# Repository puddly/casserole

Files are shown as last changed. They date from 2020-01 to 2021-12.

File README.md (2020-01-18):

# Casserole
An open source alternative to the now-defunct [Green Bean adapter](https://github.com/GEMakers/green-bean) to monitor and control GE appliances through their RJ45 port.

# Installation

```sh
# Clone the repo
git clone https://github.com/puddly/casserole
cd casserole

# Setup a new virtual Python env (optional but recommended)
python3 -m venv venv
source venv/bin/activate

# Install dependencies
pip install -r requirements.txt

# Compile and upload the firmware to your ESP32
platformio run -t upload -v -e esp32 --upload-port=/dev/cu.SLAB_USBtoUART

# Run the host software and see what your appliance is doing
python protocol.py
```

## What works
1. All bus messages are sent back to the computer, including ones sent by the appliance user input boards.
2. Messages can be sent to the bus.

## What doesn't work
1. Other devices occasionally interrupt the adapter's messages. I'm not sure how devices take turns when sending data over the bus.
2. GE/FirstBuild's open source SDK is incomplete and does not document any way to remotely start some appliances (like my washer).

## Hardware
I don't know much about building electronics but here are the parts I've used:

 - ESP32 dev kit ([I use this one with built-in RGB LEDs](https://www.tindie.com/products/ddebeer/esp32-dev-board-wifibluetooth/) but any should work)
 - 3.3v to 5V bus transceiver ([TI SN74LVC2T45](https://www.ti.com/lit/ds/symlink/sn74lvc2t45.pdf))
 - 5V regulator ([ST LD1117](https://www.st.com/content/ccc/resource/technical/document/datasheet/99/3b/7d/91/91/51/4b/be/CD00000544.pdf/files/CD00000544.pdf/jcr:content/translations/en.CD000005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), though just about any should work). I've read that the ESP32 can draw up to 600mA in 100ms bursts when in AP mode but ordinarily draws about 40mA.

Wiring:

 - Regulate the 9V from the GE bus down to 5V and connect it both your ESP32's `Vin` pin and to the high voltage input of the bus transceiver.
 - Connect the ESP32's 3.3V pin to the low voltage input of the bus transceiver.
 - Tie together the ESP32's second UART's RX and TX pins (16 and 17) and connect them to the low voltage input of the bus transceiver.
 - Connect pin 18 (though any will work) to the direction control of the bus transceiver.

```
[insert proper diagram here]
```

## Low-level details

### RJ45 Port
The RJ45 (Ethernet) port on some GE appliances exposes a bus that allows for communication with the appliance's controller board. The three pins are labeled `GND`, `COMM`, and `9V`.

The COMM bus uses 5V logic and is an inverted UART at 19,200 baud.

### Protocol
I've been unable to acquire an actual Green Bean module so all of the information here is based on what I can capture from my washing machine. Here is a sample packet:

    e2 23 22 2d f1 03 f1 2e 0e 03 03 01 19 15 05 2a 00 0a f1 76 fc 0f 0a f1 39 01 03 f1 33 01 5d 9c 30 e3 e1

All packets begin with `e2` and end with `e3 e1` (although very rarely just `e3`). The byte `e0` acts as an escape character and all instances of `e0`, `e1`, `e2`, and `e3` in the body of the packet are escaped with `e0` (so `aa e0 bb e1 cc` becomes `aa e0 e0 bb e0 e1 cc`).

Each packet has a simple structure:
 
 - (1 byte) `e2`. Everything after this but before the final `e1` is encoded using the above scheme.
 - (1 byte) packet destination
 - (1 byte) total packet length (*before* the `e[0-3]` bytes have been escaped)
 - (1 byte) packet sender
 - (1 byte) command type
 - (? bytes) data
 - (2 bytes) CRC-16 checksum of the entire packet up until the start of the checksum bytes. It is a 16-bit CRC with the following parameters:

       width=16  poly=0x1021  init=0xe300  refin=false  refout=false  xorout=0x0000  check=0x5b10  residue=0x0000  name=(none)

    As before, this is computed on the packet payload before the `e[0-3]` bytes have been escaped. Interestingly, this specific CRC-16 has the following property:

       crc16(packet_until_checksum || crc16(packet_until_checksum)) == 0x0000

 - (1 or 2 bytes) `e1 e3`, although very rarely a packet is sent (consistently) with `e3` missing.

The packet command type determines how the `data` is interpreted. A command type of `f1` is used internally for all reads/writes and has the following structure:

 - (1 byte) `f1`
 - (1 byte) number of reads/writes encoded in `data`
 - A list of commands:
   - (1 byte) `f0` is read, `f1` is write.
   - (1 byte) endpoint ID
   - (1 byte) (This and the following bytes are absent in read requests and write acknowledgements) size of read respons or data to be written
   - (? bytes) data

The Green Bean uses a different syntax for reads (writes TBD) for what it calls ERDs:

 - (1 byte) `f0`
 - (1 byte) `01` for reads
 - (2 byte) 16-bit ERD, big-endian

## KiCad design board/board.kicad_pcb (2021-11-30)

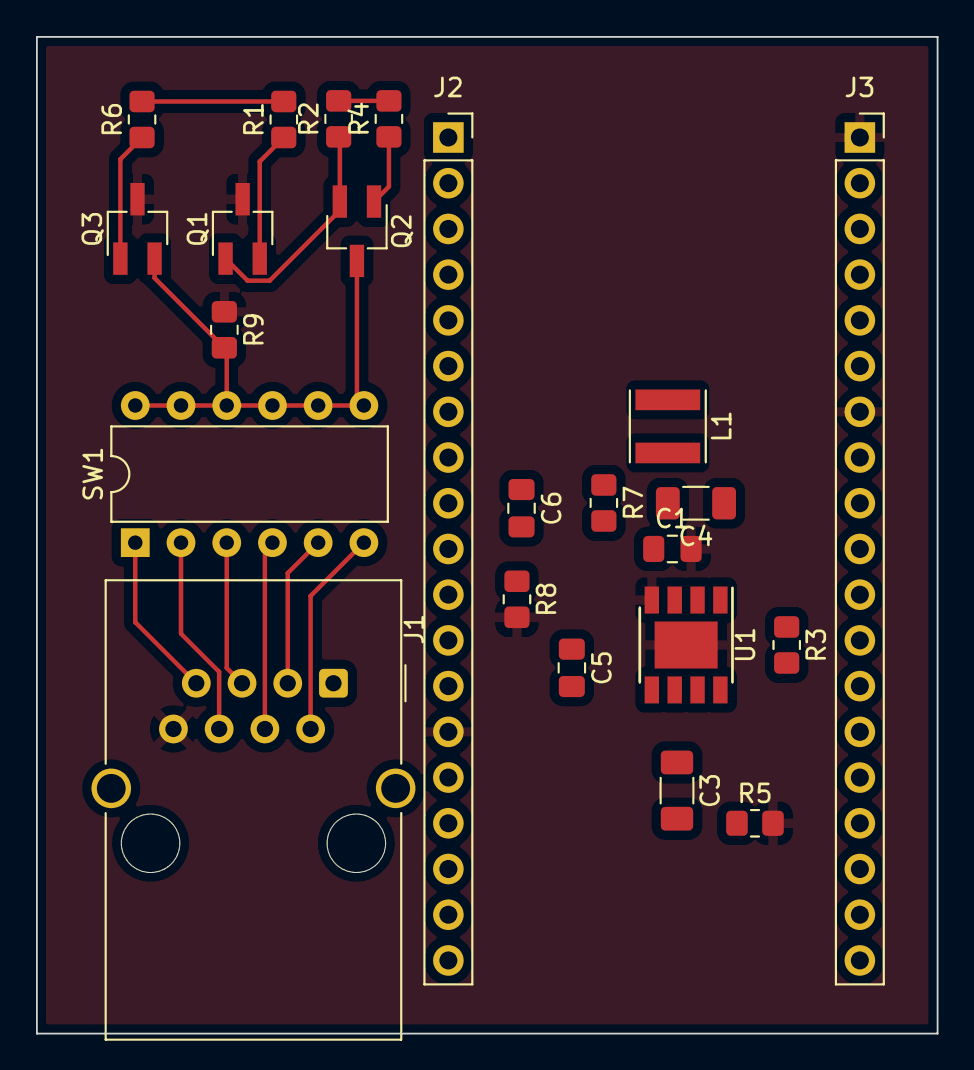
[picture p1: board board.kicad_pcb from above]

Board: 2 copper layers, 50.0 x 55.4 mm, 23 parts (0 on the bottom side), 21 nets.

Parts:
C1: 10µF; C_0805_2012Metric_Pad1.18x1.45mm_HandSolder
C3: 6.8nF; C_1206_3216Metric_Pad1.33x1.80mm_HandSolder
C4: 10nF; C_1206_3216Metric_Pad1.33x1.80mm_HandSolder
C5, C6: 22µF; C_0805_2012Metric_Pad1.18x1.45mm_HandSolder
J1: RJ45; RJ45_Wuerth_7499010001A_Horizontal
J2, J3: Conn_01x19_Female; PinSocket_1x19_P2.54mm_Vertical
L1: 10µH; L_Vishay_IFSC-1515AH_4x4x1.8mm
Q1, Q2, Q3: Q_NMOS_DGS; SC-59_Handsoldering
R1, R9: ?; R_0805_2012Metric_Pad1.20x1.40mm_HandSolder
R2, R4, R6: 47k; R_0805_2012Metric_Pad1.20x1.40mm_HandSolder
R3: 100k; R_0805_2012Metric_Pad1.20x1.40mm_HandSolder
R5: 6.8k; R_0805_2012Metric_Pad1.20x1.40mm_HandSolder
R7: 53.3k; R_0805_2012Metric_Pad1.20x1.40mm_HandSolder
R8: 10k; R_0805_2012Metric_Pad1.20x1.40mm_HandSolder
SW1: SW_DIP_x06; DIP-12_W7.62mm
U1: AP6502; Diodes_SO-8EP

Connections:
+3V3: J2.1, R1.2, R6.2
+5V: C5.1, C6.1, J2.19, L1.2, R2.2, R4.2, R7.1
GEA_3.3V_RX: J3.12, Q3.1 (D), R6.1
GEA_3.3V_TX: J3.11, Q1.2 (G), R1.1
GEA_BUS: Q2.3 (S), Q3.2 (G), R9.2, SW1.7, SW1.8, SW1.9, SW1.10, SW1.11, SW1.12
GND: C1.2, J1.8, J2.14, J3.1, J3.7, Q1.3 (S), Q3.3 (S), R5.2, R8.2, R9.1, U1.4 (GND), U1.9 (EP)
unnamed: C3.1, U1.6 (COMP)
unnamed: C3.2, R5.1
unnamed: C4.1, U1.1 (BST)
unnamed: C4.2, L1.1, U1.3 (SW)
unnamed: C5.2, C6.2, R7.2, R8.1, U1.5 (FB)
unnamed: J1.2, SW1.6
unnamed: J1.3, SW1.5
unnamed: J1.4, SW1.4
unnamed: J1.5, SW1.3
unnamed: J1.6, SW1.2
unnamed: J1.7, SW1.1
unnamed: Q1.1 (D), Q2.2 (G), R2.1
unnamed: Q2.1 (D), R4.1
unnamed: R3.2, U1.7 (EN)
VCC: C1.1, J1.1, R3.1, U1.2 (IN)

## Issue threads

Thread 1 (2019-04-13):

Comment/help

wied03, 2019-04-13:
@puddly - Have you looked @ https://github.com/GEMakers/gea-plugin-water-heater/blob/master/hewh-interface.docx ? Different appliance but might help. I analyzed a GE connect's communication with my water heater but I hadn't yet figured out 19200 baud/inverted so thanks for that piece of info.

puddly, 2019-04-14:
@wied03 I have not, thanks for the document. All of those commands and responses seem to be implemented on top of the base layer that I'm almost done figuring out so I think replacing the USB adapter will not make the main [`gea-plugin-water-heater`](https://github.com/GEMakers/gea-plugin-water-heater/) module work any differently.

wied03, 2019-04-14:
I've since found that the GE connect module does not adhere to that guide
at all. It instead follows write read commands like the SDK and your readme
mentioned. I took apart the ERD data and it worked like the SDK did.

I need to figure out the hash as well. Maybe it's just a simple checksum
like ipv4 uses?

sent from my mobile device

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

puddly, 2019-04-14:
@wied03 I've updated the README a few times, including a description of the checksum. It's implemented in the Python script that parses the packets.

Closed 2019-04-15.

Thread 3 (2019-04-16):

Sample Green Bean traffic

puddly, 2019-04-16:
I'm looking for somebody willing to donate an hour of their time (or their Green Bean for a few days) by capturing some sample USB and bus traffic from a Green Bean.

 -  For capturing the traffic from the computer to the Green Bean, you can either use [Wireshark](https://wiki.wireshark.org/CaptureSetup/USB) and capture the USB packets, or you can just patch the [Node.js module's](https://github.com/GEMakers/gea-adapter-usb/blob/master/index.js#L126) `sendPacket` and `receiveNextPacket` functions to write the sent/received data to a file.

 - For capturing the traffic to the module, you can use a $12 USB logic analyzer and [PulseView](https://sigrok.org/wiki/Downloads). I found 500KHz to be a reasonable sample rate. Just plug in the adapter and hit the <kbd>Run</kbd> button. You will somehow need to tap into the bus, which will require you to either sacrifice a short Ethernet cable and carefully cut into housing in the middle to clip into the GND (brown) and COMM (brown/white) wires:
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

   Or find some convenient place on the Green Bean to probe them, like:

    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

    There is a four-pin header on the Green Bean but it might just be for communicating with the microcontroller.

@Hixie

Hixie, 2019-04-16:
If you send me precise details for how to do it (commands and the hardware to do it), I'm happy to just do it (happy to send you money to pay for the hardware, too). Otherwise I can try to figure it out but it might be a few months as I'm rather busy at the moment.

puddly, 2019-04-16:
@Hixie  I can mail you all the required hardware if you're in the US but I can't guarantee the software will work flawlessly. If nobody else is interested and I can't figure it out by myself in the next couple of weeks, I'll send you an email.

jallen2281, 2019-05-28:
@puddly do you use facebook or another messaging service? I'd be happy to help with this as well.

puddly, 2019-05-28:
@jallen2281 I use Telegram but I've also setup a [Gitter chatroom](https://gitter.im/casserole-dev/community) that you can sign into with your GitHub account if that's easier.

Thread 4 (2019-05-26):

Designing a PCB

puddly, 2019-05-26:
My goal is to have a self-contained device that is powered by either the RJ45 port's 9V pin or by a microUSB connector that can communicate with a computer over usb or WiFi.

I'm currently using a dev kit built around the ESP32-WROOM-32 because it has:

 - two hardware UARTs (one for USB and one for communicating with the bus).
 - the UARTs support signal inversion (the bus uses 5V logic and is pulled down to 0V).
 - [first-party support](https://docs.espressif.com/projects/esp-idf/en/latest/api-reference/system/freertos.html) for FreeRTOS.
 - Bluetooth and WiFi.

I'd like wireless connectivity so I really see two ways to do this:

 - Make a "shield" for an existing dev board (e.g. the ESP32 dev kit). This saves time because pre-made dev boards already come with a voltage regulator and a USB-serial interface. All that needs to be done is to solder a few headers and a 9V->5V regulator to an unpopulated PCB. Plus the dev board can be repurposed if you ever get rid of your GE appliances.

 - Designing around a wireless module (e.g. the ESP32-WROOM-32). This would avoid having unnecessary components and will result in a simpler board but will take more time to solder together.

Component-wise, we need:

 - USB-serial converter (anything but the CH340).
 - a dual-supply transceiver for level shifting with direction and enable pins (maybe the [SN74LVC2T45](https://www.ti.com/lit/ds/symlink/sn74lvc2t45.pdf)?).
 - a component (or two) that converts 9V to both 5V and 3.3V and provides enough current for wireless operation (ESP32 needs at least 250mA, I think).
 - RJ45 port. Tying together the two possible locations of the 9V pin (the GND and COMM stay fixed) allows for handling both normal and crossover ethernet cables.

@jallen2281

mulcmu, 2020-08-10:
Here was my KiCad schematic for a "shield" using parts recommended above.  Any comments or suggestions before routing the PCB?

[OnionStraws Draft.pdf](https://github.com/puddly/casserole/files/5051666/OnionStraws.Draft.pdf)

puddly, 2020-08-10:
Thanks for the help! I've been hoping to finish this project for a while but I have no experience with actually designing PCBs so it's been a little hard to get started.

Here's some more info that I've found in the meantime:

1. Almost like I2C, the bus is being pulled down to GND by a 4.7k resistor.
   - Actively driving the bus down to GND with the chip I was originally using might not be a good idea because we can collide with another device concurrently pulling the bus up to 5V and possibly damage something. I think only pulling the bus up to 5V during transmission and letting it fall back down to GND will be a safer approach.
   - Removing the need for the SN74LVC2T45 chip reduces the cost a little.
   - Implementing collision detection by receiving and transmitting concurrently might also be a good idea, as we can just immediately stop transmitting a message if what we receive from the bus doesn't match what we expect.
   - The ESP-32's UART's RX and TX pins can be inverted in software, which might simplify the design little?

2. The input voltage on the RJ45 apparently can go as high as 16V on some appliances, not just 9V as I had measured on my machine.
   - The LD1117S50TR can't handle this high of an input voltage so we'd need a new voltage regulator.
   - Some people [have also reported](https://esp32.com/viewtopic.php?t=2662#p16066) that their off-brand ESP-32 dev kits briefly draw up to 750mA when scanning for wireless networks.

3. There are multiple footprints for the many ESP-32 dev kits available online. You can find the schematics and reference design documents for the different dev boards [on Espressif's website](https://docs.espressif.com/projects/esp-idf/en/latest/esp32/hw-reference/modules-and-boards.html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) but I think basing the design around the ESP-WROOM-32 DEVKIT V4 is or the smaller ESP32-PICO-KIT V4.1 is a good idea. They're both $10 from Digikey. Alternatively you can get a non-standard design for about $4 off of AliExpress. I'll have to investigate the footprints of the different boards a little more to see which ones are the most compatible.

mulcmu, 2020-08-11:
I've done a few custom boards for hobby stuff.  Just got a new GE Washer and Dryer.  Was looking to push cycle done and maybe time remaining to home assistant.

1.  Have you tried any alternate arrangements for RX/TX connection?  Still need something to shift from 3.3V to 5V?

2.  Looks like there are some 1A 35V linear regulators to get the 5V supply (like MC7805BDTRKGOSCT-ND).  I will look into a small DC/DC buck converter.  More parts and expense but more efficient for something powered 24/7.

3.  My generic modules from Amazon had the ESP-WROOM-32 DEVKIT V4 pinout but are a bit more compact.  The ESP module pcb antenna didn't hang out from the base PCB.

puddly, 2020-08-11:
1. The whole 5V bus with a pull-down level shifting problem is what's really tripping me up with this whole project so could you clarify what you mean by an alternate arrangement? All of the devices on the bus are 5V so I'm trying to get the ESP32 to act like everything else. I believe the official Green Bean used a pair of optocouplers for the level shifting.

2. The bus passes around data around on my machine about once per second so the larger power supply might be necessary if the ESP-32 will be transmitting frequently. I think with some sort of bus packet filters microcontroller-side it'd be possible to keep the ESP-32 in a low-power state for quite some time before it wakes up, especially if the common use case would be to just notify HA of a couple of events periodically.

3. [This is the one](https://www.tindie.com/products/ddebeer/esp32-dev-board-wifibluetooth/) I'm currently using and the PCB has a big cutout where the ESP-32's trace antenna is sitting. I'll have to compare its current draw to the Amazon ones.

puddly, 2020-09-21:
Hmm, I wasn't aware there could be multiple buses on a single RJ45. That does complicate things.

The ESP-32 definitely has enough free pins to do simultaneous TX/RX on all of those but they have to be bigbanged instead of relying on the built-in UARTs and my code doesn't really support concurrency at the moment (though the ESP-32 has first-party support for FreeRTOS, which should make the rewrite trivial).

mattgallion, 2021-11-30:
Hey guys,

I just bought a W&D and am interested in integrating into Home Assistant too. I have a lot of experience with PCB design so I can help with layout and can do some board runs too.

puddly, 2021-11-30:
Thanks for your interest!

I've just pushed my attempt at a schematic and an unrouted board to the Git repo under the `board/` folder.  It was draw up with a KiCad nightly build so it may not open properly with the current stable release.

Unfortunately, a recent package theft has left me without any 5V regulators capable of accepting 9V-16V input (and I won't be able to get replacements until early next year due to the chip shortage) so this project is not seeing much attention these days.

The only portion of the PCB that I'm still struggling with at the moment is the inverted level shifting with the GE bus pulldown.  If you can suggest a way to do this while accepting "normal" logic levels from the microcontroller, I think the hardware is close to being done. At least in the eyes of someone who has designed exactly two PCBs with no active components 😄.

---

Attached is the schematic in case there are any custom symbols/footprints on the board that don't open:

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

jallen2281, 2021-11-30:
I was chatting with a GE repair man today and he uses a "Black Bean" module. It has firmware flashing capabilities as well as everything the green bean has. Just thought it was interesting.

jallen2281, 2021-11-30:
Not sure if this will help someone, but the chip in use on the original module is this: https://www.microchip.com/en-us/product/PIC24FJ256GB106

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

mattgallion, 2021-12-02:
@puddly Any reason why you're using a switching regulator for the 5V instead of a linear regulator? I assume your goal is to minimize losses in power, and I'm curious if you know what the current supply capability from the bus is?

I had started my own attempt based on some ideas I found online (https://circuitcellar.com/resources/ee-tips/one-wire-rs-232-half-duplex-ee-tip-135/) but havent tested anything yet. See attached schematic, it's **by no means complete**. I used a dual inverter to fix the inverted levels, and a digital isolator for the level shifting.

@jallen2281 Thats funny, I was working on my own adapter (copying from the greenbean) and I was going to call it blackbean.

[BlackBeanSchematic_0.1.pdf](https://github.com/puddly/casserole/files/7644192/BlackBeanSchematic_0.1.pdf)

puddly, 2021-12-02:
> I assume your goal is to minimize losses in power, and I'm curious if you know what the current supply capability from the bus is?

I don't, unfortunately. I will poke around in my washer when I get a minute.

My understanding is that the ESP32 draws about 40mA when not actively using WiFi, 150mA when using WiFi, and briefly exceeds 500-700mA when scanning for networks.  The worst case scenario would be regulating 16V down to 5V and supplying 150mA of current, so a linear regulator would dissipate at least 1.65W.

> I used a dual inverter to fix the inverted levels, and a digital isolator for the level shifting.

Thanks for the link, I wish I had found that page sooner. I think your schematic incorporates design 3 in that article, which suppresses the "local echo". For collision detection, loopback reception is actually desirable because the firmware would compare each transmitted character (or bit) to the received one and stop transmitting if they aren't identical.

> Thats funny, I was working on my own adapter (copying from the greenbean) and I was going to call it blackbean.

I believe there's also a Navy Bean.  This is arguably the most important part of the project but thankfully there are [many other beans to choose from](https://en.wikipedia.org/wiki/Bean#Common_genera_and_species_of_beans).  An irregular, kidney shaped PCB with red solder mask might be interesting...

mulcmu, 2021-12-09:
> Looks like the hardware & interface has been changed. My RJ45 port doesn't have pin 7 populated. I was still getting 14 Vdc between pin 1 & 8. It appears pins 3 to 6 all could have connections to the main PCB. Haven't hooked it up to a scope yet...

Finally hooked it up to scope.  Pins 3 & 4 seemed to have a constant 5V and 5 & 6 were at ground with a bit of noise.  I couldn't detect anything that looked like a signal.  I ordered a `U+ CONNECT MODULE PBX23W00Y0` to try to get some insight into what was going on with this alternate interface.

mulcmu, 2022-01-04:
I've made some progress on getting my dryer integrated into HA.  It has the half duplex GE bus on pin 7 of the RJ45.  I didn't have luck with mosfet based level shifting using 2N7000 or TXS0104E level shifting IC.   Finally got rx & tx working on breadboard with dryer using non-inverting buffer IC.
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

I was using a adjustable DC/DC switching module for the 5v power supply (https://www.amazon.com/gp/product/B01MQGMOKI/).  The dryer was able to power both the ESP32 and `U+CONNECT MODULE`  at the same time.

ESPHome custom component and full schematic are posted here https://github.com/mulcmu/esphome-ge-dryer-uart

Looks like my washer might have the full duplex GE bus so trying to integrate both configurations into one PCB.

mightymos, 2022-06-13:
GTW460ASJ6WW (washer) with RJ45 GEA3 pinout shown:
[GTW460ASJ6WW_Washer_WiringDiagram.pdf](https://github.com/puddly/casserole/files/8894653/GTW460ASJ6WW_Washer_WiringDiagram.pdf)

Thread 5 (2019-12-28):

RJ45 pinout?

Zebble, 2019-12-28:
Is the RJ45 pinout documented anywhere?

It was a mentioned that one of the issues with communication is not knowing/being able to control who has control of the bus, which results in colliding/lost messages.  Any chance there might be some sort of flow control going on on other pins on the RJ45?

puddly, 2019-12-28:
The RJ45 connector, at least on my machine, physically has only three populated pins: 9V, GND, and a single data pin. The rest of the connector is just empty plastic. I've drawn out a crude diagram in the other open issue: https://github.com/puddly/casserole/issues/3#issue-433554335

Does yours look different?

puddly, 2019-12-28:
Here's a picture of what I mean:

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

Closed 2020-01-08.

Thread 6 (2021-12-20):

U+ Connect Module Info / Captures

mulcmu, 2021-12-20:
The U+ Connect module (GE Part# PBX23W00Y0) provides cloud based interface to select appliances.   Module is in a small plastic case with a single push button and led on front, RJ45 port for connection to appliance, and internal magnets to secure product in rear housing.  It comes with a 12-inch Ethernet cable to connect to appliance.  FCC ID is ZKJ-WCATC001, report is [here](https://apps.fcc.gov/oetcf/eas/reports/ViewExhibitReport.cfm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).

Connected it to my dryer for initial testing.  The Android app to establish the connection is quite buggy, lots of random closes/crashes and not very responsive.  Basic status for dryer settings were passed back to the app.  It did not seem to support turning dryer on remotely.  It had an option and confirmation dialog box to turn dryer off remotely but this function didn't actually work.  Pin 7 had the expected19200 serial traffic.  Here was sample [capture](https://github.com/puddly/casserole/files/7742249/dryer.capture.txt) of the traffic.

PCB photos:
Top
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
Bottom1:
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
Bottom2:
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

puddly, 2021-12-20:
Thanks for the pictures.

I'm seeing only six instances of the start-of-packet byte `E2` in your capture. Did you invert the RX pin when capturing over serial? If you have an FTDI USB-serial adapter, it can be done with their FT prog utility:

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

mulcmu, 2021-12-21:
I was using RealTerm.  The invert option was not checked yesterday.

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

puddly, 2021-12-21:
It's not a software tweak, it's something done in firmware or hardware. The serial data sent by the bus can erroneously be interpreted as "normal" serial but it isn't usable data.

mulcmu, 2021-12-21:
I managed to get an ESP32 hooked up to log the serial data remotely with [custom ESPHome UART](https://github.com/mulcmu/esphome-ge-dryer-uart).  (Don't have to lug laptop to laundry now.)  It is configured with the UART inverted in hardware.  Only the RX is hooked up currently.  Here were a few captures.  Looks like `e2` and `e3` for packet start and end are coming across.
[capture1.txt](https://github.com/puddly/casserole/files/7758909/capture1.txt)
[capture2.txt](https://github.com/puddly/casserole/files/7758910/capture2.txt)
[captur3e.txt](https://github.com/puddly/casserole/files/7758911/captur3e.txt)

puddly, 2021-12-23:
I've re-written a large portion of the code. Try it out:

```console
$ virtualenv -p 3.9 venv
$ source venv/bin/activate
$ git clone https://github.com/puddly/casserole
$ pip install -e ./casserole
$ cat capture2.txt | python -m casserole.tools.parser
2021-12-22 20:51:27 ubuntu.local __main__[48214] DEBUG RX: <E2 24 0B BE F0 01 20 12 56 3F E3 E1>
2021-12-22 20:51:27 ubuntu.local __main__[48214] INFO Parsed: <GEAFrame(src=0xBE, dst=0x24, payload=<F0 01 20 12>, ack=True>
2021-12-22 20:51:27 ubuntu.local __main__[48214] INFO Parsed payload: <ERDCommand(command=<ERDCommandID.READ: 0xF0>, erds=[0x2012:None])>
2021-12-22 20:51:27 ubuntu.local __main__[48214] DEBUG RX: <E2 BE 0D 24 F0 01 20 12 01 01 AC 66 E3 E1>
2021-12-22 20:51:27 ubuntu.local __main__[48214] INFO Parsed: <GEAFrame(src=0x24, dst=0xBE, payload=<F0 01 20 12 01 01>, ack=True>
2021-12-22 20:51:27 ubuntu.local __main__[48214] INFO Parsed payload: <ERDCommand(command=<ERDCommandID.READ: 0xF0>, erds=[0x2012:<01>])>
2021-12-22 20:51:27 ubuntu.local __main__[48214] DEBUG RX: <E2 24 08 BE F3 1C 31 E3 E1>
2021-12-22 20:51:27 ubuntu.local __main__[48214] INFO Parsed: <GEAFrame(src=0xBE, dst=0x24, payload=<F3>, ack=True>
2021-12-22 20:51:27 ubuntu.local __main__[48214] WARNING Failed to parse ERD: <F3>
...
```

The packets are also a little unstructured so I think yours is using the [GEA1 protocol](https://github.com/doitaljosh/ge-appliances-re/blob/master/reverse-engineering.txt#L22), like my washer. There's apparently now a GEA2 and GEA3.

The utility decodes bytes read from lines over stdin, so you can feed it any data as long as it looks something like this (must contain `uart_debug` and have hex bytes after `<<<`):

```
uart_debug <<< BF 0B 24 A0 01 60 03 9B 51 E3
```

mulcmu, 2022-01-14:
Looks like my washer is GEA3.  Here was a sample capture using two uarts on ESP32 to capture both lines between U+ and the washer.  Uarts configured for 230400 baud but not inverted.

[wcap1.txt](https://github.com/puddly/casserole/files/7866704/wcap1.txt)

The casserole parser has been very useful for decoding.
[wcap1.out.txt](https://github.com/puddly/casserole/files/7866705/wcap1.out.txt)

BillyCroan, 2025-02-01:
I want to apologize that this might not be the best place for this question, but I just connected a U+Connect module  pbx23w00y0 to my GE gtw845cpndg clothes washer, with a standard Ethernet cable, and it seems to have fried the washer!

I checked the connector for dust, and it is clean.  I also tested the cable and it is wired normally.  I noticed on the back of the washer, pins 2 and 7 are missing.  But all 8 pins on the adapter are present.  Is there any hope to reset or recover the control board in the washer?  a hard reset procedure or something?  I can tell that the washer when plugged in is drawig about 0.1 watt. So at least its psu is in tact.

The washer already had wifi and it shows 'OFFLINE' in SmartHQ.  I bought the module hoping for better control of it remotely.  Instructions say to hold the button on the module down until its LED lights.  how long should that take?

stboch, 2025-02-02:
@BillyCroan correct this isn't really the place. Not sure what caused it to not work. Did you unplug the washer prior to connecting the module?

Have you tried a reset by unplugging the device for 3 minutes. I would also hold the start button for 10 seconds while the washer is unplugged.

BillyCroan, 2025-02-02:
Thank you Stephen!  I agree here is not the right place, and at the same time I struggle to think of any other place (as odd as this is) that I might find technically minded individuals familiar with the electronic deisgn of GE appliances who aren't employed by GE to say "warranty expired, buy a new one"

No.  I did not unplug the AC power supply prior to trying to connect the module.  no documentation on/with the module or on the washer suggested doing that.

I suppose I (poorly) assumed that a heavy appliance designed to handle caustic chemicals and water would be resilient enough for the RJ45 port on the back of it (which is usually used in hot-plug-capable systems, and not labeled on either GE device as not-hot-plug-able) to be hot-plug-able.  If for instance, the U+Connect module were a card that went in a slot with a card-edge connector, I probably would have de-energized the unit before connecting.

Hopefully documenting my experience might save another person from inadvertent damage by hot plugging.

I did try leaving it unplugged overnight last night and then held the power and then the "play" buttons in for 10 seconds to drain caps, then plugging it back in and still no response.

I could imagine that the RJ45 connector on the back would have a 5v and gnd pin on it that if shorted together would deprive the control board of its operating voltage.  But on close inspection, there is no deformity or contamination in that port nor on the cable used.  Perhaps the U-Connect device itself was defective and caused a short.

I will probably disassemble both in short order and check for shorts or blown fuses.  I'd hope that there's a 5v fuse on the board maybe. though that feels wishful at best.

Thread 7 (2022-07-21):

ge dishwasher traffic samples and transmit question

jeremyplichta, 2022-07-21:
I have been referring to your repo and [ge-appliances-re](https://github.com/doitaljosh/ge-appliances-re) to try to understand how to read traffic directly from the UART COM pin exposed in the RJ45 in my GE dishwasher. The ultimate goal is to be able to read and set the "personality" on the UI board as they seem to ship without being configured correctly.

I am using a logic/protocol analyzer that is directly hooked up to the comm pin. It is able to read some traffic that appears to be in the right format.

```
E2 40 0D BF F5 01 60 03 01 00 55 3A E3 E1
E2 BF 08 40 F5 94 B9 E3 E1 FF FF FF FF FF FF
E2 BF 0B 40 F0 01 60 03 7E B0 E3 E1
E2 BF 0C 40 F2 01 60 03 00 72 9E E3 E1
E2 BF 08 40 01 3B 22 E3 E1
E2 40 0D BF F0 01 60 03 01 00 16 3B E3 E1
E2 40 0B BF F2 01 60 03 6C 06 E3 E1
E2 40 0C BF 01 00 00 05 24 40 75 E3 E1
E2 40 0D BF F5 01 60 03 C0 00 55 3A E3 E1
```

My protocol analyzer can also easily transmit UART as well. I am trying to find some sort of message I can transmit that will be acknowledged by the board and be sent back to me with the address I specify (1A) as the destination.

The following message is an attempt to send a subscribe request to 0x46 (the UI board as described [here](https://github.com/doitaljosh/ge-appliances-re/blob/master/reverse-engineering.txt#L22) ) for ERD 0x300C (the personality ERD according to [this](https://github.com/GEMakers/gea-plugin-dishwasher/blob/master/index.js#L106). I don't seem to receive any sort of specific response after sending this:

```
E2 46 0B 1A F2 01 30 0C 3B 40 E3 E1
````

Am I thinking about this in the right way? Sending a subscribe request to a specific destination in hope of receiving a READ reply with the contents of that ERD? Any other tips on what I should do to troubleshoot? I wish I had one of those greenbean devices but in the meantime would be happy just getting the board to acknowledge one of my messages.

mulcmu, 2022-07-22:
It looks to me like you are on the right track.  In your sample traffic capture, there are messages between addresses `40` and `BF`.  Your UI board might be on address `40` and not `46`.

You can send a broadcast message to `FF` to request firmware revision levels as a start to confirm analyzer is connected.  `E2, FF, 08, BB, 01, 9A, 85, E3`   Expected response would be a packet from `40` to `BB` and `BF` to `BB`, maybe more if there are other boards on the bus.  See [here](https://github.com/doitaljosh/ge-appliances-re/blob/master/appliance-interfaces/hawk-dryer-interface.docx) for more info.

It would be better to use the `F0` read ERD instead of `F2` to subscribe to ERD.  Some ERDs do not allow subscriptions to be setup.  (Also, the `E1` is an acknowledgment from the destination address.  If the packets with the subscribed ERD data are not acknowledged then the source will cancel the subscription.)

My experience showed that the boards don't respond unless the checksum is correct.  Your sample packet checksum looked correct to me, so a response would be expected if ui board address was `46`, ERD `300C` exists, and allows subscription.

Here is what I got for `F0` read packets for `40` and `46`:
`E2, 46, 0B, 1A, F0, 01, 30, 0C, D6, 28, E3`
`E2, 40, 0B, 1A, F0, 01, 30, 0C, 77, 0D, E3`

jeremyplichta, 2022-07-22:
Thanks for the response! I was under the incorrect impression that a `F0` indicated a "READ" response of a certain ERD and that the sender included the additional `E1`s on the end of each message. This clears it up and hopefully unblocks me!

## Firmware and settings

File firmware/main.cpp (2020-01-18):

#include <Arduino.h>
#include <HardwareSerial.h>

#include "bus_reader.h"
#include "serial_reader.h"


constexpr uint32_t SERIAL_BAUD = 115200;

constexpr uint32_t BUS_BAUD = 19200;
constexpr uint32_t BUS_SEND_DELAY_MICROS = 13000;  // min. quiet time before transmitting


#ifdef ESP32
	// ESP-32 hardware serial
	#define ge_serial Serial2

	constexpr uint8_t BUS_DIR_PIN = 18;
	constexpr uint8_t BUS_COMM_RX_PIN = 16;  // These are tied together
	constexpr uint8_t BUS_COMM_TX_PIN = 17;  // These are tied together
#elif ESP8266
	#include <SoftwareSerial.h>

	SoftwareSerial ge_serial;

	constexpr uint8_t BUS_DIR_PIN = D1;
	constexpr uint8_t BUS_COMM_RX_PIN = D2;  // D5
	constexpr uint8_t BUS_COMM_TX_PIN = D2;  // D2; SoftwareSerial supports one-wire

	#error "RX does not work yet, sorry :("
#else
	#error "Unsupported board!"
#endif



namespace CasseroleMessage {
	// Server -> Client
	constexpr uint8_t BUS_MESSAGE = 0x01;
	constexpr uint8_t BUS_ERROR = 0x03;

	// Client -> Server
	constexpr uint8_t SEND_BUS_MESSAGE = 0x11;
	constexpr uint8_t SEND_BUS_MESSAGE_ACK = 0x12;
	constexpr uint8_t SEND_BUS_MESSAGE_ERR = 0x13;

	constexpr uint8_t SEND_BUS_MESSAGE_TX = 0x02;

	// Misc
	constexpr uint8_t PING = 0xFF;
	constexpr uint8_t HEARTBEAT = 0xFE;
	constexpr uint8_t DEBUG = 0xDE;
};


void send_to_computer(uint8_t type, uint8_t size, uint8_t *payload) {
	uint8_t buffer[0xFF];

	if (size > 0xFF - 4) {
		// This should not happen
		assert(false);
		return;
	}

	buffer[1] = (uint8_t)((size & 0xFF00) >> 8);
	buffer[2] = (uint8_t)((size & 0x00FF) >> 0);
	buffer[3] = type;

	for (uint8_t i = 0; i < size; i++) {
		buffer[4 + i] = payload[i];
	}

	buffer[4 + size] = 0x00;  // Trailing null byte

    uint8_t index_of_last_zero = 0;

    for (uint8_t offset = 1; offset < size + 4; offset++) {
        if (buffer[offset] == 0x00) {
            buffer[index_of_last_zero] = offset - index_of_last_zero;
            index_of_last_zero = offset;
        }
    }

    buffer[index_of_last_zero] = 4 + size - index_of_last_zero;

	Serial.write(buffer, 4 + size + 1);

	// Timing for these messages isn't that important
	Serial.flush();
}

void send_to_computer(uint8_t type) {
	send_to_computer(type, 0x00, nullptr);
}

void set_transmit(bool tx) {
	// HIGH on DIR pin is A -> B
	// LOW  on DIR pin is B -> A
	// Switching time is no more than 30ns so a 1000ns delay should be plenty
	if (tx) {
		digitalWrite(BUS_DIR_PIN, HIGH);
		delayMicroseconds(1);

		#ifdef ESP8266
			ge_serial.enableTx(true);
		#endif
	} else {
		digitalWrite(BUS_DIR_PIN, LOW);
		delayMicroseconds(1);

		#ifdef ESP8266
			ge_serial.enableTx(false);
		#endif
	}
}

void setup() {
	Serial.begin(SERIAL_BAUD);

	while (!Serial) {
		// Hardware serial isn't ready yet
	}

	set_transmit(false);
	pinMode(BUS_DIR_PIN, OUTPUT);

	if (BUS_COMM_RX_PIN != BUS_COMM_TX_PIN) {
		pinMode(BUS_COMM_RX_PIN, INPUT);
		pinMode(BUS_COMM_TX_PIN, OUTPUT);
	} else {
		// One-wire mode
		pinMode(BUS_COMM_RX_PIN, INPUT);
		pinMode(BUS_COMM_TX_PIN, INPUT);
	}

	set_transmit(false);

	#ifdef ESP32
		ge_serial.begin(BUS_BAUD, SERIAL_8N1, BUS_COMM_RX_PIN, BUS_COMM_TX_PIN, true, 0);
	#elif ESP8266
		ge_serial.begin(BUS_BAUD, SWSERIAL_8N1, BUS_COMM_RX_PIN, BUS_COMM_TX_PIN, true, 0, 0);
		ge_serial.enableTx(false);  // start off in RX
	#else
		#error "Unsupported board!"
	#endif

	delay(500);
	send_to_computer(CasseroleMessage::PING);
	delay(500);
}


void loop() {
	/*
	 * Read a packet from the bus
	 */
	static BusReaderState bus_reader_state;
	static uint32_t last_byte_time = 0;

	uint32_t now = micros();

	// Only read if there is data to read
	if (ge_serial.available()) {
		last_byte_time = now;

		BusReaderResult bus_read_result = read_bus_byte(bus_reader_state, ge_serial);

		switch (bus_read_result.result) {
			case BusReaderResult::INVALID:
				// Send out an error
				send_to_computer(CasseroleMessage::BUS_ERROR, strlen(bus_read_result.message), (uint8_t*)bus_read_result.message);
				send_to_computer(CasseroleMessage::DEBUG, bus_reader_state.size, bus_reader_state.body);

				bus_reader_state.reset();
				break;

			case BusReaderResult::READING:
				// Do nothing
				break;

			case BusReaderResult::VALID:
				// We have a valid packet!
				send_to_computer(CasseroleMessage::BUS_MESSAGE, bus_reader_state.size, bus_reader_state.body);
				bus_reader_state.reset();
				break;

			default:
				assert(false);
				break;
		}
	}


	// Keep track of the last byte's timestamp
	uint32_t bus_delta = now - last_byte_time;



	/*
	 * Read a packet from the serial connection and send it to the bus, if possible
	 */

	// We sometimes won't have time to send a packet this loop iteration
	static bool waiting_to_send = false;
	static bool resync = false;
	static SerialReaderState serial_reader_state;

	if (waiting_to_send) {
		uint8_t payload_size = serial_reader_state.get_payload_size();
		uint8_t* payload = serial_reader_state.get_payload();

		switch (serial_reader_state.get_type_from_header()) {
			case CasseroleMessage::PING:
				send_to_computer(CasseroleMessage::PING);

				serial_reader_state.reset();
				waiting_to_send = false;
				break;

			case CasseroleMessage::SEND_BUS_MESSAGE:
				// We can't send anything until it's been quiet for enough time
				if (bus_delta < BUS_SEND_DELAY_MICROS) {
					break;
				}

				// Enable TX
				set_transmit(true);

				// Write the Header
				ge_serial.write(payload, 3);

				// We handle escaping/unescaping in here so the computer-side code never deals with it
				for (uint8_t i = 3; i < payload_size - 2; i++) {
					uint8_t byte = payload[i];

					if ((byte == 0xE0) || (byte == 0xE1) || (byte == 0xE2) || (byte == 0xE3)) {
						// Escape the byte before writing it
						ge_serial.write(0xE0);
					}

					ge_serial.write(byte);
				}

				// Write the footer
				ge_serial.write(payload + (payload_size - 2), 2);

				// Flush before we disable transmission
				ge_serial.flush();

				// Disable TX
				set_transmit(false);

				// We just sent a packet so reset the timer
				last_byte_time = micros();
				send_to_computer(CasseroleMessage::SEND_BUS_MESSAGE_TX);

				serial_reader_state.reset();
				waiting_to_send = false;
				break;

			default:
				// Invalid message type, discard
				send_to_computer(CasseroleMessage::SEND_BUS_MESSAGE_ERR);
				serial_reader_state.reset();
				waiting_to_send = false;
				break;
		}
	} else {
		if (Serial.available()) {
			uint8_t byte = Serial.read();

			if (resync) {
				// We use COBS to turn null bytes into frame delimiters
				if (byte == 0x00) {
					resync = false;
				}
			} else {
				SerialReaderResult serial_read_result = read_serial_byte(serial_reader_state, byte);

				if (serial_read_result.result == SerialReaderResult::READING) {
					// Do nothing
				} else if (serial_read_result.result == SerialReaderResult::INVALID) {
					serial_reader_state.reset();

					send_to_computer(CasseroleMessage::SEND_BUS_MESSAGE_ERR, strlen(serial_read_result.message), (uint8_t*)serial_read_result.message);

					// Something is wrong, wait until the next frame to try again
					resync = true;
				} else if (serial_read_result.result == SerialReaderResult::VALID) {
					// Handle this case above
					waiting_to_send = true;
					send_to_computer(CasseroleMessage::SEND_BUS_MESSAGE_ACK);
				} else {
					assert(false);
				}
			}
		}
	}
}

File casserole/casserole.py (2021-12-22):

import sys
import enum
import asyncio
import inspect
from io import BytesIO
from collections import defaultdict

import coloredlogs
import async_timeout
import serial_asyncio
from verboselogs import VerboseLogger
from gea.protocol import GEBusPacket, GEBusMessageCommands, pretty_bytes, read_exactly

LOGGER = VerboseLogger(__name__)


class CasseroleError(ValueError):
    pass


class TinyCOBS:
    @staticmethod
    def encode(data):
        assert len(data) <= 0xFF - 2
        data = bytes(data) + b"\x00"

        index_of_last_zero = 0
        result = bytearray([0x00] * (1 + len(data)))

        for offset in range(len(data)):
            byte = data[offset]

            if byte == 0x00:
                result[index_of_last_zero] = offset - index_of_last_zero + 1
                index_of_last_zero = offset + 1
            else:
                result[offset + 1] = byte

        return result

    @staticmethod
    def decode(data):
        assert 2 <= len(data) <= 0xFF

        output = bytearray([0x00] * (len(data) - 1))
        next_zero_in = data[0]

        for offset in range(len(data) - 1):
            next_zero_in -= 1
            byte = data[offset + 1]

            if next_zero_in == 0:
                output[offset] = 0x00
                next_zero_in = byte

                if offset + next_zero_in > len(data):
                    raise ValueError("Invalid zero pointer")
            else:
                output[offset] = byte

        return output[:-1]


class CasseroleMessage:
    class Commands(enum.Enum):
        BUS_MESSAGE = 0x01
        BUS_ERROR = 0x03

        SEND_BUS_MESSAGE = 0x11
        SEND_BUS_MESSAGE_ACK = 0x12
        SEND_BUS_MESSAGE_ERR = 0x13
        SEND_BUS_MESSAGE_TX = 0x02

        PING = 0xFF
        HEARTBEAT = 0xFE
        DEBUG = 0xDE

    def __init__(self, type, payload):
        self.type = type
        self.payload = payload

    @property
    def size(self):
        return 1 + 1 + len(self.payload) + 2

    def to_bytes(self):
        result = b""
        result += self.size.to_bytes(1, "big")
        result += self.type.value.to_bytes(1, "big")
        result += self.payload
        result += GEBusPacket.crc16(result).to_bytes(2, "big")

        assert GEBusPacket.crc16(result) == 0x0000

        return result

    @classmethod
    def from_file(cls, f):
        size = int.from_bytes(read_exactly(f, 2), "big")
        type = cls.Commands(int.from_bytes(read_exactly(f, 1), "big"))
        payload = read_exactly(f, size)

        return cls(type, payload)

    @classmethod
    def from_bytes(cls, data):
        f = BytesIO(data)
        message = cls.from_file(f)
        remaining = f.read()

        if remaining:
            raise ValueError(f"Unused data remains at the end: {remaining}")

        return message

    def __repr__(self):
        return f"<{self.__class__.__name__}(type={self.type}, payload={self.payload})"


class EventBus:
    def __init__(self):
        self.listeners = defaultdict(list)

    def on(self, key, callback=None):
        if callback is not None:
            self.listeners[key].append(callback)
            return

        def inner(function):
            self.listeners[key].append(function)
            return function

        return inner

    def emit(self, key, *args, **kwargs):
        for callback in self.listeners[key]:
            if inspect.iscoroutinefunction(callback):
                asyncio.create_task(callback(*args, **kwargs))
            else:
                callback(*args, **kwargs)

    def off(self, key, callback):
        if callback in self.listeners[key]:
            self.listeners[key].remove(callback)


class CasseroleProtocol(asyncio.Protocol):
    def __init__(self):
        super().__init__()

        self.transport = None
        self.send_lock = asyncio.Lock()

        self.events = EventBus()
        self.received_messages = defaultdict(asyncio.Queue)

        self._buffer = b""
        self._wait_for_resync = False

        @self.events.on("packet:casserole")
        def casserole_handler(message):
            if message.type == CasseroleMessage.Commands.BUS_MESSAGE:
                packet, remaining = GEBusPacket.from_bytes(message.payload)
                assert not remaining

                self.events.emit("packet:ge", packet)
            elif message.type == CasseroleMessage.Commands.SEND_BUS_MESSAGE_ERR:
                LOGGER.error("Caught an error: %s", message.payload)

        states = defaultdict(lambda: defaultdict(bytes))

        @self.events.on("packet:ge")
        def ge_handler(message):
            if message.command != 0xF1:
                LOGGER.warning("Unknown command type: %x", message.command)
                return

            KNOBS = 0x2D
            BOARD = 0x23

            if message.source in (KNOBS, BOARD) and message.destination in (
                BOARD,
                KNOBS,
            ):
                commands = GEBusMessageCommands.from_bytes(message.data)

                important = message.destination == 0x23 and any(
                    ep == 0x2E for _, ep, _ in commands.commands
                )

                for command, endpoint_id, data in commands.commands:
                    if (
                        command == GEBusMessageCommands.Commands.WRITE
                        and data is not None
                    ):
                        # This is some kind of rolling counter
                        if endpoint_id == 0x33:
                            continue

                        current_value = states[message.destination][endpoint_id]

                        if not important and current_value == data:
                            continue

                        if important or not (
                            message.source == 0x23
                            and message.destination == 0x2D
                            and endpoint_id == 0x19
                        ):
                            LOGGER.debug(
                                "%x wrote to %x endpoint %x=[%s]",
                                message.source,
                                message.destination,
                                endpoint_id,
                                pretty_bytes(data),
                            )

                        states[message.destination][endpoint_id] = data
                    elif (
                        command == GEBusMessageCommands.Commands.READ
                        and data is not None
                    ):
                        current_value = states[message.source][endpoint_id]

                        if not important and current_value == data:
                            continue
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

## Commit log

2019-04-22 Added error packets to wrapper protocol and simplified packet parser in firmware.
    [main.cpp, protocol.py]
2019-04-27 Transmission now works but crashes after ~10s.
    [main.cpp, protocol.py]
2019-05-09 Migrated to an ESP32 with chips for signal inversion and level shifting.
2019-05-10 Able to (briefly) control indicator lights on washer. No luck simulating the start button yet.
2021-11-30 Add WIP KiCad board files
    [board.kicad_pcb, board.kicad_sch]
